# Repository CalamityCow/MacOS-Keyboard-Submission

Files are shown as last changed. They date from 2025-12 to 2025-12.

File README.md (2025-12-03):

# MacOS-Keyboard-Submission

This project is just a simple MacOS keyboard, although honestly you can modify any keyboard to beomce a MacOS keyboard by changing its firmware. 
I started this project because I thought it would be fun to learn how to design a PCB and solder electronic components. While I'm mostly a software guy I've really wanted to learn the electronical side of things for a while now so after discovering blueprint I thought it would be a great idea to get some experience. I used a template from ScottoKeebs, which included the MCU and the power supply prewired.
## Features
The main features of this keyboard are:
- 95 keys
- 6 macro keys
- 101 per-key leds
- volume knob

Later on I want to try to add a LCD screen to the keyboard and some hubs.

# PCB and Schematic
The PCB and schematic were designed using KiCad. It is a standard 2 layer design.
Screenshot 2025-12-02 at 10 13 27 PM
Screenshot 2025-12-02 at 10 13 40 PM
Screenshot 2025-12-02 at 10 13 53 PM
Screenshot 2025-12-02 at 10 14 31 PM
Screenshot 2025-12-02 at 10 14 37 PM

Below is the case for my keyboard.
Screenshot 2025-12-02 at 10 17 44 PM
Screenshot 2025-12-02 at 10 17 24 PM

Onshape link: https://cad.onshape.com/documents/4c8306176f584344784f98ef/w/69e2811755be6605c0c07897/e/ae6883cfd18f4e06578fb81e

# Bom
BOM link: https://docs.google.com/spreadsheets/d/1dYup_cxLSYAhRu9MLTjsDp3llwcmy9G50tkykbGbxao/edit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

|LCSC Items |FIELD2 |FIELD3 |FIELD4 |FIELD5 |FIELD6 |FIELD7 |FIELD8 |FIELD9|FIELD10 |FIELD11 |FIELD12 |FIELD13 |
|---|---|---|---|---|---|---|---|---|---|---|---|---|
|Index |LCSC# |MPN |Manufacturer |Package |Description |RoHS |Quantity |MOQ |Multiple|Unit Price($)|Extended Price($)|Product Link |
|1 |C23733 |CL05A475MP5NRNC |Samsung Electro-Mechanics|402 |10V 4.7uF X5R ±20% 0402 Ceramic Capacitors RoHS |yes |50 |50 |50 |0.0048 |0.24 |https://www.lcsc.com/product-detail/C23733.html  |
|2 |C2827654 |USBLC6-2SC6 |TECH PUBLIC |SOT-23-6 |6A 12V 150W 6V Unidirectional 5V SOT-23-6 TVS Diodes RoHS |yes |10 |10 |10 |0.0384 |0.38 |https://www.lcsc.com/product-detail/C2827654.html|
|3 |C5446 |XC6206P332MR-G |TOREX |SOT-23-3L |Positive Fixed 3.3V SOT-23-3L Voltage Regulators - Linear, Low Drop Out (LDO) Regulators RoHS|yes |5 |5 |5 |0.1033 |0.52 |https://www.lcsc.com/product-detail/C5446.html |
|4 |C354152 |SN74AHCT125N |TI |DIP-14 |1 4.5V~5.5V 4 DIP-14 Buffers, Drivers, Receivers, Transceivers RoHS |yes |1 |1 |1 |0.684 |0.68 |https://www.lcsc.com/product-detail/C354152.html |
|5 |C470754 |EC11E15244B2 |ALPSALPINE |Through Hole |Through Hole Encoders RoHS |yes |1 |1 |1 |1.9975 |2 |https://www.lcsc.com/product-detail/C470754.html |
|6 |C115351 |SKQGABE010 |ALPSALPINE |SMD-4P,5.2x5.2mm|12V 5.2mm Round Button 5.2mm SPST 50mA SMD-4P,5.2x5.2mm Tactile Switches RoHS |yes |5 |5 |5 |0.1076 |0.54 |https://www.lcsc.com/product-detail/C115351.html |
|7 |C2073614 |PNM0402E5000BST1 |VISHAY |402 |50mW 500Ω 75V ±25ppm/℃ Thin Film Resistor ±0.1% 0402 Chip Resistor - Surface Mount RoHS |yes |2 |1 |1 |1.4497 |2.9 |https://www.lcsc.com/product-detail/C2073614.html|
|8 |C25905 |0402WGF5101TCE |UNI-ROYAL |402 |5.1kΩ 62.5mW 50V ±100ppm/℃ Thick Film Resistor ±1% 0402 Chip Resistor - Surface Mount RoHS |yes |100 |100 |100 |0.0005 |0.05 |https://www.lcsc.com/product-detail/C25905.html  |
|9 |C25744 |0402WGF1002TCE |UNI-ROYAL |402 |10kΩ 62.5mW 50V ±100ppm/℃ Thick Film Resistor ±1% 0402 Chip Resistor - Surface Mount RoHS |yes |100 |100 |100 |0.0006 |0.06 |https://www.lcsc.com/product-detail/C25744.html  |
|10 |C165948 |TYPE-C-31-M-12 |Korean Hroparts Elec |SMD |1 16P Type-C SMD USB, DVI, HDMI Connector Assemblies RoHS |yes |5 |5 |5 |0.1752 |0.88 |https://www.lcsc.com/product-detail/C165948.html |
|11 |C210357 |MF-FSMF050X-2 |BOURNS |603 |6V 500mA 40A 1A 100mΩ 0603 PTC Resettable Fuses RoHS |yes |20 |20 |20 |0.0359 |0.72 |https://www.lcsc.com/product-detail/C210357.html |
|12 |C60474 |CC0402KRX7R7BB104 |YAGEO |402 |16V 100nF X7R ±10% 0402 Ceramic Capacitors RoHS |yes |200 |100 |100 |0.0009 |0.18 |https://www.lcsc.com/product-detail/C60474.html  |
|13 |C5149201 |SK6812MINI-E |OPSCO Optoelectronics |SMD |SMD LED Addressable, Specialty RoHS |yes |105 |5 |5 |0.0683 |7.17 |https://www.lcsc.com/product-detail/C5149201.html|
|14 |C52923 |CL05A105KA5NQNC |Samsung Electro-Mechanics|402 |25V 1uF X5R ±10% 0402 Ceramic Capacitors RoHS |yes |100 |100 |100 |0.003 |0.3 |https://www.lcsc.com/product-detail/C52923.html  |
|15 |C15195 |CL05B103KB5NNNC |Samsung Electro-Mechanics|402 |50V 10nF X7R ±10% 0402 Ceramic Capacitors RoHS |yes |100 |100 |100 |0.0014 |0.14 |https://www.lcsc.com/product-detail/C15195.html  |
|16 |C307331 |CL05B104KB54PNC |Samsung Electro-Mechanics|402 |50V 100nF X7R ±10% 0402 Ceramic Capacitors RoHS |yes |100 |100 |100 |0.0038 |0.38 |https://www.lcsc.com/product-detail/C307331.html |
|17 |C81720 |STM32F072CBT6 |ST |LQFP-48(7x7) |ARM Cortex-M0 48MHz 37 LQFP-48(7x7) Microcontrollers RoHS |yes |1 |1 |1 |1.3444 |1.34 |https://www.lcsc.com/product-detail/C81720.html  |
|18 |C84410 |1N4148TR |onsemi |DO-35 |4A 4ns 100V 1V@10mA 200mA DO-35 Single Diodes RoHS |yes |150 |50 |50 |0.0155 |2.33 |https://www.lcsc.com/product-detail/C84410.html  |
|19 |C15008 |CL31A107MQHNNNE |Samsung Electro-Mechanics|1206 |6.3V 100uF X5R ±20% 1206 Ceramic Capacitors RoHS |yes |10 |10 |10 |0.0552 |0.55 |https://www.lcsc.com/product-detail/C15008.html  |
|Sub Total | | | | | | | | | | |21.36 | |
|Shipping and Taxes | | | | | | | | | | |10 | |
|Line Total | | | | | | | | | | |31.36 | |
| | | | | | | | | | | | | |
|Mechincalkeyboards.com Items | | | | | | | | | | | | |
|Index |Manufacturer  |Item |Quantity |Multiple |Unit Price($) |Extended Price($)|Product Link | | | | | |
|1 |Kailh |Kailh Switch Hot Swap Socket |110 |10 |0.11 |12.1 |https://mechanicalkeyboards.com/products/kailh-switch-hot-swap-socket?variant=47416807194924 | | | | | |
|2 |Cherry |Cherry MX Silent Black 60g Linear Switch |110 |10 |0.5 |55 |https://mechanicalkeyboards.com/products/cherry-mx-silent-black-60g-linear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| | | | | |
|Sub Total | | | | | |67.1 | | | | | | |
|Shipping and Taxes | | | | | |0 | | | | | | |
|Line Total | | | | | |67.1 | | | | | | |
| | | | | | | | | | | | | |
|McMaster-Carr Items | | | | | | | | | | | | |
|Index |Manufacturer  |Item |Quantity |Multiple |Unit Price($) |Extended Price($)|Product Link | | | | | |
|1 |McMaster-Carr |Adhesive-Back Polyurethane Rubber Bumpers  |1 (pack of 72) |1 |4.77 |4.77 |https://www.mcmaster.com/95495K931/ | | | | | |
|2 |McMaster-Carr |Uncoated High-Speed Steel Chip-Clearing Tap|1 |1 |13.94 |13.94 |https://www.mcmaster.com/3192N11/ | | | | | |
|Sub Total | | | | | |4.77 | | | | | | |
|Shipping and Taxes | | | | | |0 | | | | | | |
|Line Total | | | | | |18.71 | | | | | | |
| | | | | | | | | | | | | |
|JLC PCB | | | | | | | | | | | | |
|Index |Manufacturer  |Item |Quantity |Multiple |Unit Price($) |Extended Price($)| | | | | | |
|1 |JLC |PCB |1 |5 |62.9 |62.9 | | | | | | |
|Sub Total | | | | | |62.9 | | | | | | |
|Shipping and Taxes | | | | | |0 | | | | | | |
|Line Total | | | | | |62.9 | | | | | | |
| | | | | | | | | | | | | |
|Grand Total | | | | | |180.07 | | | | | | |
|Grand Total after 7.25% tax estimate| | | | | |193.125075 | | | | | | |

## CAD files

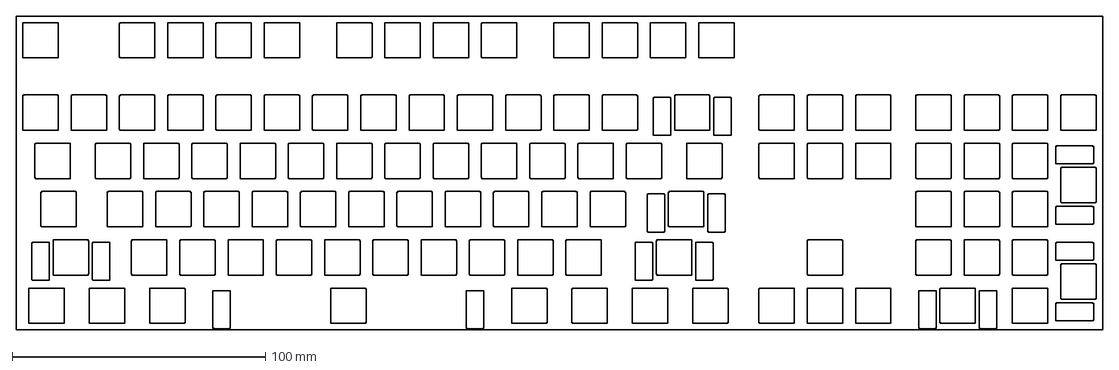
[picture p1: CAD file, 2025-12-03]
CAD/plate.dxf
428.6 x 123.8 mm

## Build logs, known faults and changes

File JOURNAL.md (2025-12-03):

# Total Time: 46.5 hours

# Day 1: Brainstorming and first concepts.
## 11/21/2025
Here is my starting idea:

Screenshot 2025-12-02 at 10 30 39 PM

- 100% mechanical keyboard
- Hot swappable
- LCD(probably to save cost) screen display
- 2 USB 3.0
- 2 USB C
- 1 microSD reader
- 1 ethernet port

I'd like to have an aluminum case for my keyboard but since it will likely have to be custom, I'm not too sure how to machine one. (Also it seems that nobody sells 100% shells anyways)

## 1.0 hour

# Day 2: Deciding parts and starting the PCB schematic
## 11/22/2025
Today I did a lot of research on the components and I decided on using the STM32F072CBT6 as my main control unit for the keyboard as it was plenty of GPIO pins and more than enough processing power for a keyboard. Then to run the hubs and display, I will use a raspberry pi 2 to handle that. Using https://www.keyboard-layout-editor.com/#/ I generated my keyboard outline with dimensions to guide my PCB.



This was my first time using KiCAD so I spent a lot of time on research, today I was only able to wire the schematic for the MCU



I found this guide here that was very useful for learning keyboard design and KiCAD: https://www.youtube.com/watch?v=8WXpGTIbxlQ&list=PLBD2IS_t_iWZDMdG_ZF57x9Ebm3kxKqxF&index=3

## 4.5 hours

# Day 3: Finishing the Schematics and building the PCB
## 11/23/2025
After following the really nice guide I found, I was able to finish the schematic for all the modules. In total, I have:

MCU + Power supply

Screenshot 2025-11-24 at 11 00 52 AM

Keyboard matrix

Screenshot 2025-11-24 at 12 14 33 AM

LED panel

Screenshot 2025-11-24 at 12 14 51 AM

Screenshot 2025-11-24 at 12 15 04 AM

Volume Knob

Screenshot 2025-11-24 at 12 15 19 AM

After I used my keyboard layout to add the keys to the PCB



Since the LCD screen is hooked up to a separate microcontroller, I think I will add it later as it is easy and modular to add.

## 9.0 hours

# Day 4/5: Routing the PCB
## 11/25/2025
I went on a flight so I couldn't really work on the project the left few days but I'm finally back. Today I started hooking up the switches on the keyboard and adding the LEDS in.



My matrix routing is quite simple, but I took a bit of time to figure out the routing for LEDS as I had to try my best to avoid EMI. I think that this configuration for LEDS will work:



Though it is a bit time consuming so it will probably take me two more days to finish the routing.



Also, I decided to use a rotary encoder instead of a potentiometer for the volume knob as its probably easier to code later.

## 3.0 hours

# Day ???????: Finished the PCB!
## 11/30/2025
This is going to be a long one...
I did not do a single journal last week as I was on Thanksgiving break. Luckily between my time spent on airplane flights, car rides, and general downtime, I was able to put in an honestly absurd amount of time.

I decided that a screen + hubs is WAY too hard for my first project, so I will do them later as an add on.

For LEDS, I decided to switch from WS2812B to sk6812mini e because they are reverse mounted. Also I switched my diode placements to the top of the switches to allow for more space on my LED traces.

Speaking of LED traces, I must have messed this part up at least 3 times. First, I used the wrong footprint, then I accidently routed them all in parallel, before finally routing them together correctly.

Enough yapping here is my finished PCB:





And my schematics:




## 20.0 hours

# Day ???? + 1: Case design
## 12/1/2025
I made some minor changes to the model by making the fill zone look neater and putting components closer to the center of the board.

Making the case was quite easy because I generated my keyboard layout with a DXF file of the outline using these two links:
https://www.keyboard-layout-editor.com/
https://kbplate.ai03.com/

All I did was import the DXF as a sketch to Onshape then add 3 layers of offsets.



Next I extruded the plate and the casings.



I decided to do a top mount design, and I will use some 3dp spacers to support my the pcb. (I dont think grip strength of the mounts is enough to hold the pcb)



Finally on the bottom, I added an angle attachment and rubber stoppers. The idea is that the triangle is able to be changed so that I can 3dp many different angles to see what fits for me.



As for the case itself I want it to be acrylic or aluminum, but I will 3dp the first few iterations with PETG so that I can get a good design first.



# 6.0 hours

# Finishing details on case + BOM
## 12/2/2025
Added a usb cutout for a usb wire.


I also inserted all the needed bolts and nuts. Most of my holes will be tapped and then screwed together with a 0 80 screw. (I hate metric)

Finally I added the step file of my PCB to make sure everything will fit together.


Here is my BOM: https://docs.google.com/spreadsheets/d/1dYup_cxLSYAhRu9MLTjsDp3llwcmy9G50tkykbGbxao/edit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

## 2.0 hours

# Quick Update
## 12/2/2025
CHANGED ALL THE HOLES BACK TO METRIC >:(
0 80 was WAYY to expensive

Screenshot 2025-12-02 at 9 46 58 PM

I think changing my screws from 0 80 to M3 dropped the BOM cost by 20-30. Also I have random m3 screws at home and robotics lmao.
# 1.0 hour

As a quick sidenote I didn't realize I had to add a jornual markdown so as I was copying my jornual from the Blueprint website too here, I realize that I sound progressively more insane in each entry.

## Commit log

2025-12-03 Revise README for updated CSV and BOM information
    Updated README with new CSV file link and BOM details.
2025-12-03 Revise BOM section and fix formatting issues
    Updated BOM section with new item listings and corrected formatting.
2025-12-03 Document Day 2: Parts selection and PCB schematic
    Added details about Day 2 of the project, including component choices and schematic progress.
2025-12-03 Remove power supply and MCU image from JOURNAL.md
    Removed an image of the power supply and MCU from the journal.
2025-12-03 Update JOURNAL.md with Day 4/5 project details
    Documented progress on Day 4/5, including keyboard switch connections and LED routing considerations.
2025-12-03 Update JOURNAL.md with PCB completion details
    Documented progress on PCB design and changes to components.
2025-12-03 Add journal entry for case design on 12/1/2025
    Documented case design process and changes made to the model.
2025-12-03 Update JOURNAL.md with case finishing details
    Added details about case design, USB cutout, and BOM.
2025-12-03 Add quick update on screw changes and BOM
    Updated journal with metric screw changes and BOM cost reduction.
2025-12-03 Used STL bc STEP too big
